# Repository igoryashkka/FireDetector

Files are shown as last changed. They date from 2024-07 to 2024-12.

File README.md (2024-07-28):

# FireDetector

## PCB and 3D-Design

| 3D-Design | PCB |
|:---:|:---:|
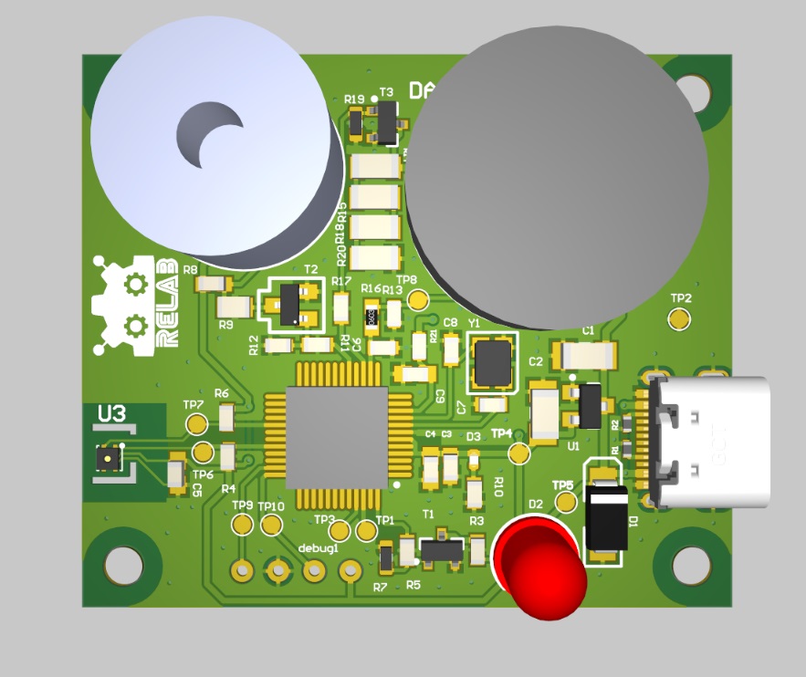
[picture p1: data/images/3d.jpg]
Input image
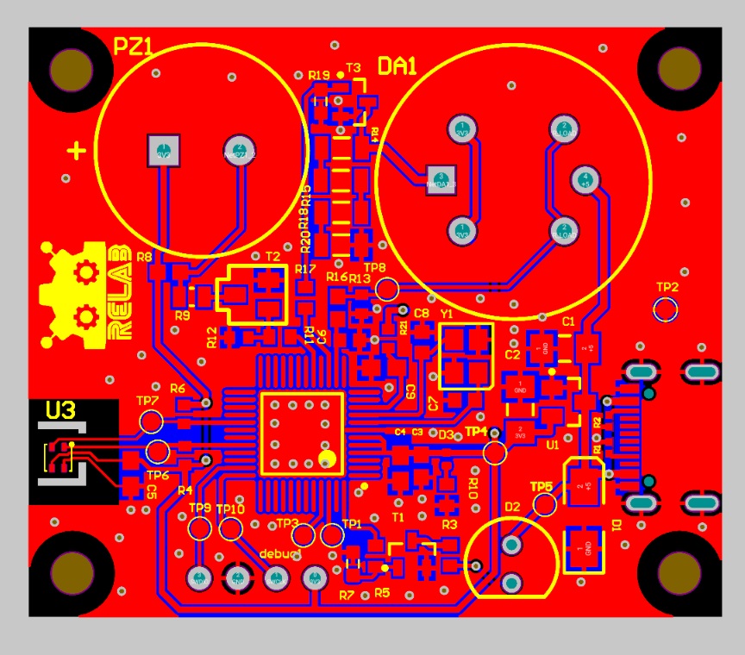
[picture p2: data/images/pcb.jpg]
Predicted mask
|  |  |

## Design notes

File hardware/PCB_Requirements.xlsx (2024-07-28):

PCB Name | Fire Detector |  | <Parameter PCB_Version not found>
Author | Ihor Yashan
Amount boards per stand | 1
Produced within | 2 weeks
Item | Requirement | Comment
Layer count | 2
Size | 42.7х38.9mm
Thickness | 1.6 mm
Material | FR-4
Min track/spacing | 0.17mm / 6mil
Min hole size | 0.3 mm
Copper weight | 1oz / 35um
Mask | on both sides
Mask color | Black
Surfaces finishing | HASL
Silkscreen | Yes
Silkscreen color | White
Board Outline, Cutout | Mechanical4 (GM4)
Electric test | Necessarily for 100% samples

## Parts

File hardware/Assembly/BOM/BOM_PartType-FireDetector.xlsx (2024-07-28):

Comment | Description | Designator | Footprint | LibRef | Quantity
100u 1206 | Multilayer Ceramic Capacitor, C Series, 100u F, - 20%, X5R, 10 V, 1206 | C1, C2 | PCB-3930564-3 | CMP-3930564-3 | 2
2.2u 0603 | Ceramic Multilayer Capacitor, 0603 C 2.2uF ,10 VDC, +125degC, X7R Dielec, +/-10% | C3 | PCB-uly74adw9ajmyngyt4c8-1 | CMP-ceff04ea830e1138-1 | 1
100n 0603 | 0603 100nF 16 V ±10% Tolerance X7R Surface Mount Multilayer Ceramic Capacitor | C4, C5, C9 | AVX 0603YC104KAZ2A | CMP-126706-3 | 3
10n 0603 | Ceramic Capacitor, Multilayer, Ceramic, 50V, 10% +Tol, 10% -Tol, X7R, 15% TC, 0.01uF, Surface Mount, 0603 | C6 | CAPC1608X90X35LL15T15 | CMP-175274-2 | 1
10p 0603 | Multilayer Ceramic Capacitor, 10 pF, 50 V, ± 5%, C0G (NP0), 0603 | C7, C8 | CAPC1608X87X35NL15T15 | CMP-4049010-3 | 2
Bourns SMAJ5.0CA | Transient Voltage Suppressor, TVS, SMAJ Series, Bidirectional, 5 V, DO-214AC, 2, 6.4 V | D1 | PCB-vtu3u1mnbo50t4of4vtk-1 | CMP-282675-5 | 1
Lite-On LTL-4223 | @LED, RED, DIFFUS, 635nm, T-1 3/4, 19mcd, VIEWING ANGLE: 36, T/REEL | D2 | PCB-jn1d7xm0frbkcgbx1k6p-1 | CMP-82c94bcbc4355d0e-4 | 1
LTST-C281KGKT | Standard LEDs - SMD SMD LED Green 571nm 35mcd 130VA 0402 | D3 | PCB-vktc7y19lroxdehs8mxv-1 | CMP-873e4eb91e2758f9-12 | 1
MQ7 | Analog Carbon Monoxide Sensor https://www.sparkfun.com/products/9403 | DA1 | sensor mq-7-Footprint-1 | CMP-a3e36b8373d07c24-5 | 1
Global Connector Technology USB4105 | Conn USB 2.0 Type C RCP 16 POS 0.3mm/0.5mm Solder RA SMD 16 Terminal 1 Port T/R | J1 | PCB-jtoj50qxusyca8vax1pa-1 | CMP-02a6cdcbf5c5dd61-15 | 1
TDK PS1420P02CT | Audio Buzzer Piezo 30Vo-p 5Vo-p 70dBA Through Hole Pin Ammo | PZ1 | PCB-snegfq1spk96rguke62s-1 | CMP-0cb8c507bf0ed37f-8 | 1
56k 0402 | Res Thick Film 0402 56K Ohm 1% 0.063W(1/16W) ±100ppm/C Pad SMD Automotive T/R | R1, R2 | PCB-q54nzy04w6wuwzvyrr10-1 | CMP-740bb86d8397abcc-1 | 2
150ohm 0603 | SMD Chip Resistor, 150 Ohm, ± 1%, 100 mW, 0603 [1608 Metric], Thin Film | R3 | RESC1608X55X30NL15T15 | CMP-3651093-2 | 1
10k 0603 | SMD Chip Resistor, 10 kOhm, ± 1%, 100 mW, 0603 [1608 Metric], Thick Film CRG0603F10K/10 | R4, R6, R12, R13, R21 | RESC1608X55X30LL15T15 | CMP-1974d512ef63c6b3-3 | 5
1k 0603 | SMD Chip Resistor, 1 kOhm, ± 1%, 330 mW, 0603 [1608 Metric], Thick Film,CHP0603-FX-1001ELF | R5, R10, R11, R17 | RESC1608X55X30NL20T10 | CMP-2823488-2 | 4
100k 0603 | Res Thick Film 0603 100K Ohm 1% 0.1W(1/10W) ±100ppm/C Pad SMD T/R | R7, R19 | PCB-js3e944hkesj3cskg8px-1 | CMP-47e38e6423219824-1 | 2
100ohm 0603 | SMD Chip Resistor, 100 Ohm, ± 1%, 100 mW, 0603 [1608 Metric], Thick Film RC0603FR-13100RL | R8 | CAPC1608X90X35NL15T15 | CMP-cc630402cb1d13a4-1 | 1
0ohm 0805 | RES SMD 0.0 OHM JUMPER 1/8W 0805 | R9 | RESC2013X50X30LL20T20 | CMP-1904075-2 | 1
22ohm 1206 | SMD Chip Resistor, 22 Ohm, ± 1%, 250 mW, 1206 [3216 Metric], Thick Film RC1206FR-0722RL | R14, R15, R18, R20 | RESC3216X70X50LL05T20 | CMP-3707874-2 | 4
200ohm 0603 | SMD Chip Resistor, 200 Ohm, ± 1%, 100 mW, 0603 [1608 Metric], Thick Film, General Purpose | R16 | CAPC1608X90X35NL15T15 | CMP-dd0d170937a802ca-2 | 1
IRLML6244TRPBF | Single N-Channel 20 V 1.3 W 8.9 nC HexFet Power Mosfet Surface Mount - SOT-23-3 | T1, T3 | PCB-05ns9k6nv0txgfjo8w7e-1 | CMP-7c86b4929b0ea341-4 | 2
BC847B,215 | TRANS NPN 45V 0.1A SOT23 | T2 | SOT23-BEC | CMP-856282-5 | 1
Torex Semiconductor XC6206P332MR | Low ESR Cap. Compatible Positive Voltage Regulator | U1 | SOT23-3 | CMP-3784183-12 | 1
STMicroelectronics STM32G030C8T6 | MCU 32-Bit STM32G030 ARM Cortex-M0+ RISC 64KB Flash 2V to 3.6V 48-Pin LQFP Tray | U2 | STM-LQFP48_M | CMP-eb4c2469bd74348b-7 | 1
SHT41 | SHT4x Series 3.6 V 80% RH 4th Generation Digital Humidity and Temperature Sensor | U3 | PCB-dp4eo4jstscfxnaq393n-1 | CMP-893b468f277b56fc-2 | 1
8Mhz 3.2 x 2.5 x 0.8mm_x0008__x0008__x0008__x0008__x0008__x0008_ | Abracon ABM8AIG-8.000MHZ-8-V1R-T Crystal Crystal 0.031 0.80mm -40C~150C 500Ohm | Y1 | ABM8AIG-4-Lead | CMP-76f4bbcd6863a933-3 | 1

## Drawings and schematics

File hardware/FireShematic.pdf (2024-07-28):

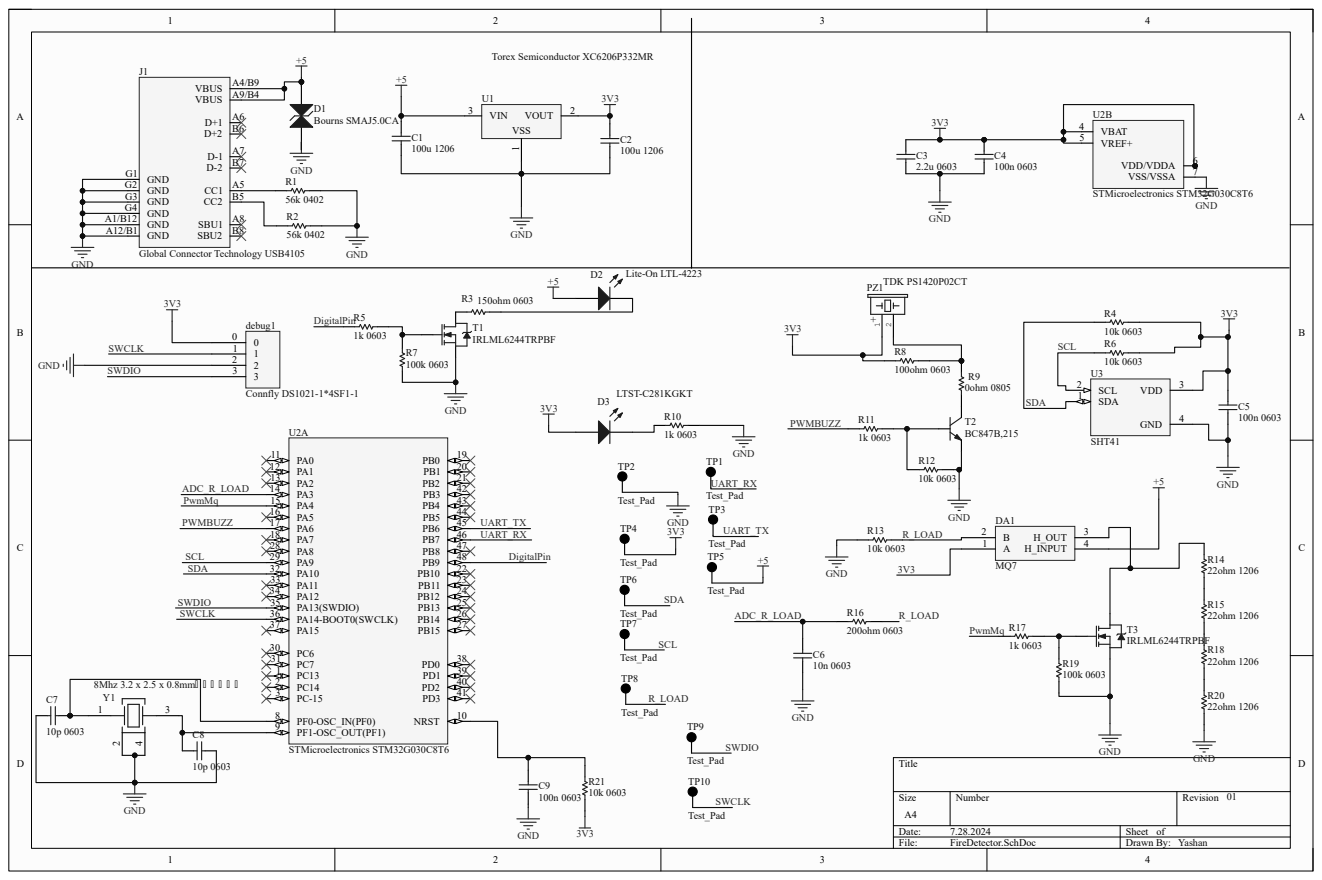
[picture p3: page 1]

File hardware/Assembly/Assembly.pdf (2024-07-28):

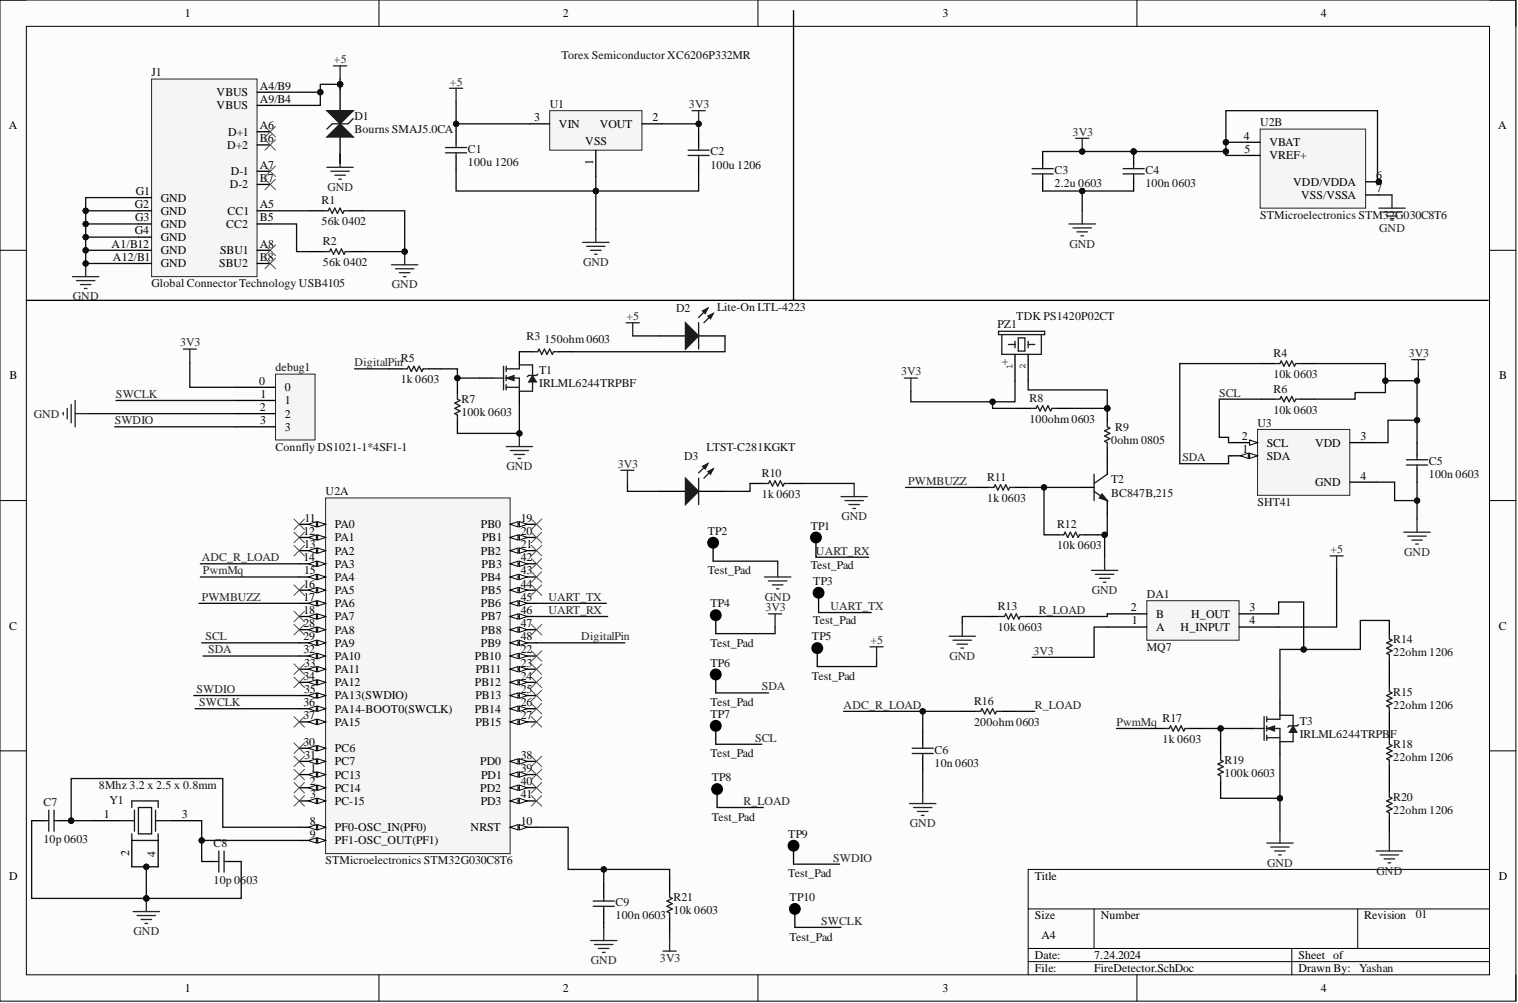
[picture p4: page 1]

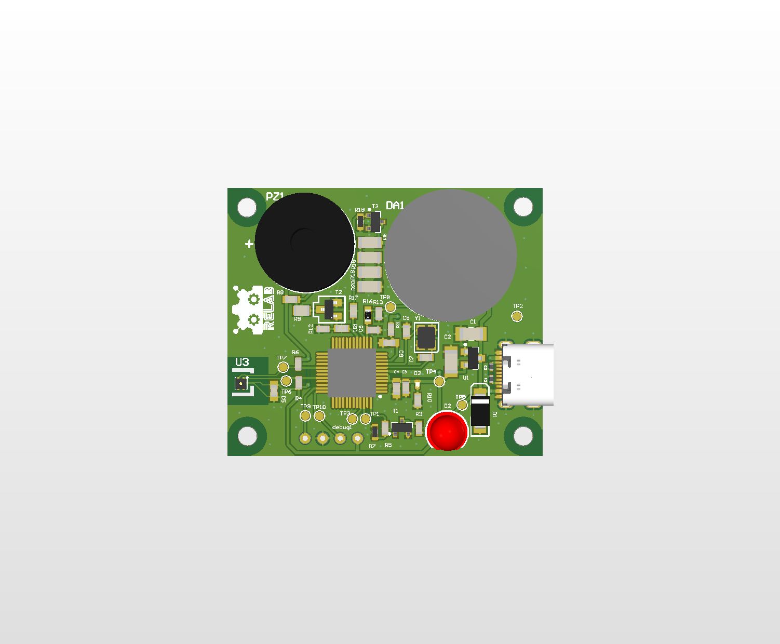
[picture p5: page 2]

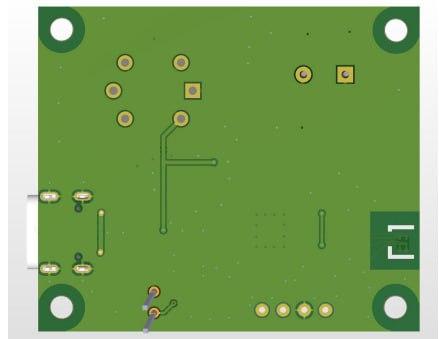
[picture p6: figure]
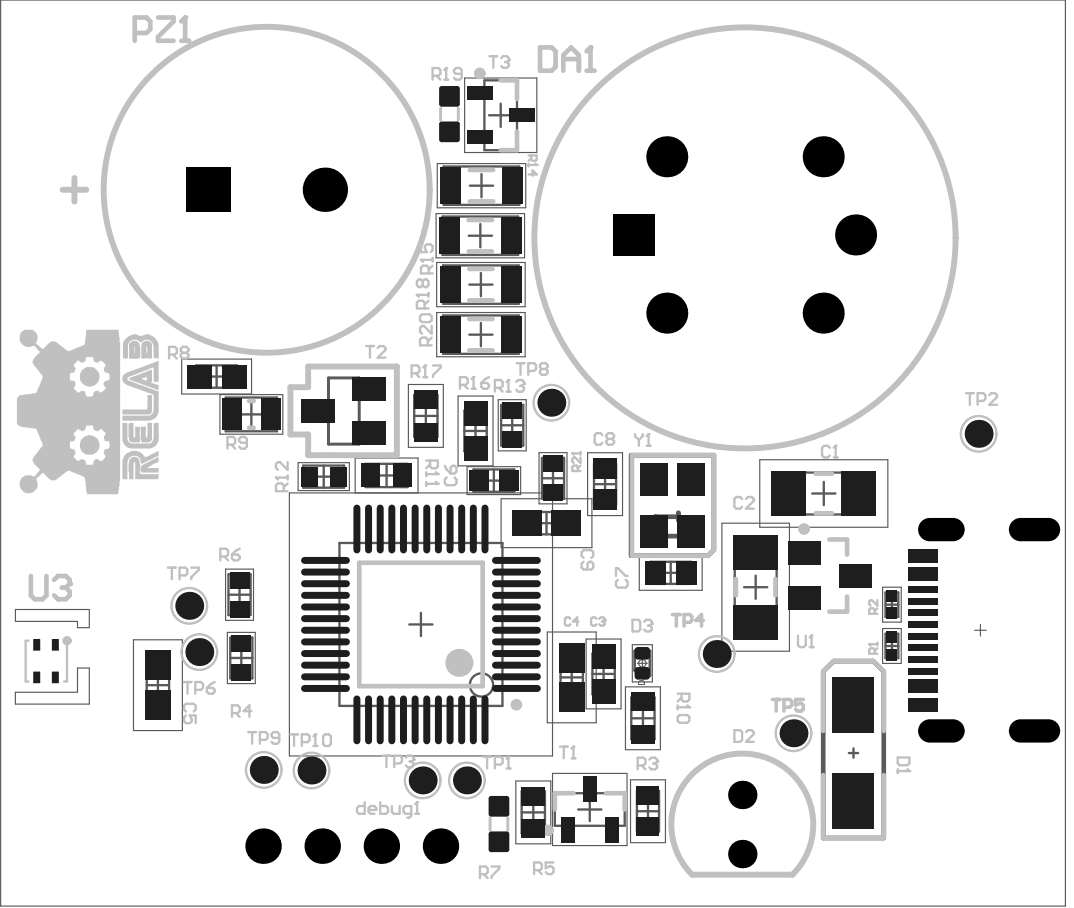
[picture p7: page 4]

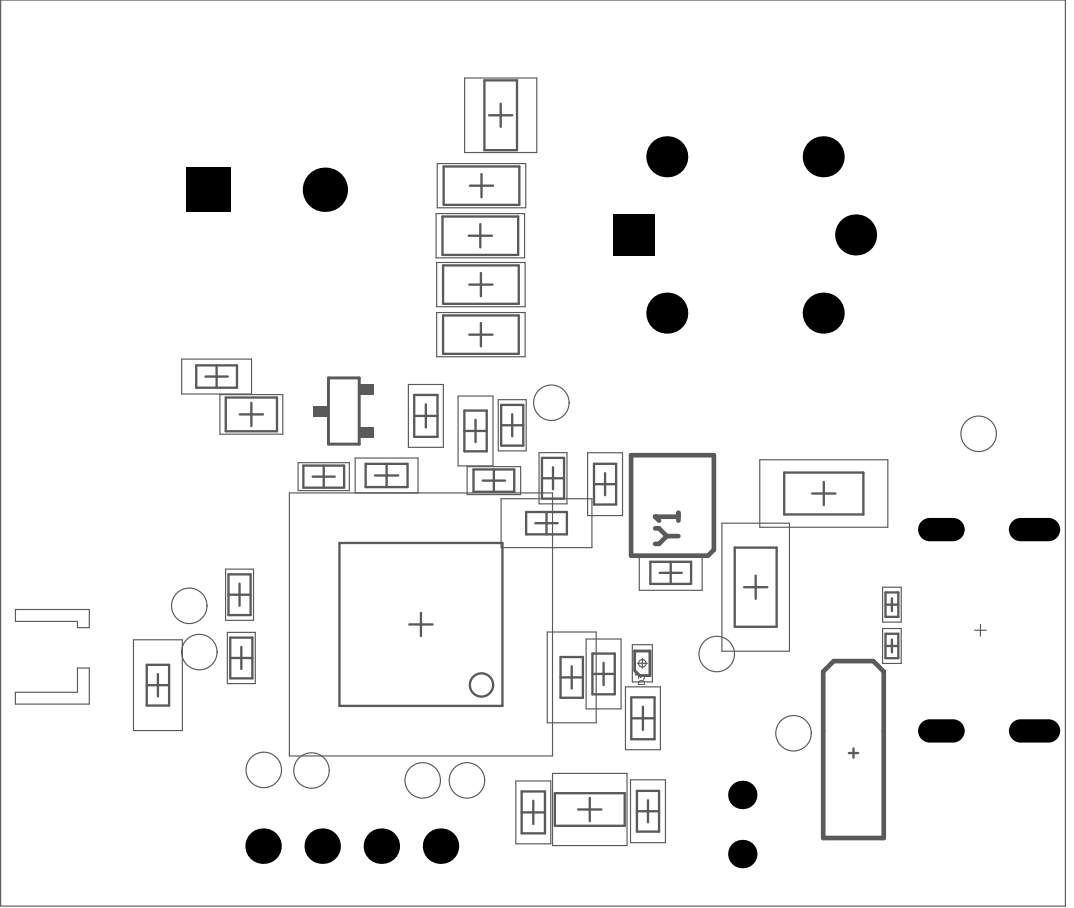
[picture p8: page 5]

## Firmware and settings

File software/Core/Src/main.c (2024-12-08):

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
/* Includes ------------------------------------------------------------------*/
#include "main.h"
#include <stdio.h>
#include <string.h>
/* USER CODE BEGIN PD */
#define LIMIT_TEMP 		50
#define LIMIT_CO_PPM 	150
#define LIMIT_HUMIDITY 	30

#define TEMP_ANOMALY_THRESHOLD     10
#define CO_ANOMALY_THRESHOLD       20
#define HUMIDITY_ANOMALY_THRESHOLD 10
#define ANOMALY_INTERVAL           3000

#define HEATER_INTERVAL 21600000  				// 6 hours
#define HEATER_RUN_TIME 10000    				// 10 seconds


uint32_t value_ppm = 0;								// Global var used in driver_mq.c
uint8_t can_process_uart = 1;

uint8_t uart1_rx_buffer[SIZE_UART_RX_BUFFER] = {0};
char uart_command[SIZE_UART_RX_BUFFER] = {0};
uint8_t uart_command_ready = 0;

/* USER CODE END PD */

ADC_HandleTypeDef hadc1;

I2C_HandleTypeDef hi2c1;

TIM_HandleTypeDef htim1;
TIM_HandleTypeDef htim3;
TIM_HandleTypeDef htim14;
TIM_HandleTypeDef htim16;
TIM_HandleTypeDef htim17;

UART_HandleTypeDef huart1;

void SystemClock_Config(void);
static void MX_GPIO_Init(void);
static void MX_TIM17_Init(void);
static void MX_TIM16_Init(void);
static void MX_ADC1_Init(void);
static void MX_I2C1_Init(void);
static void MX_TIM14_Init(void);
static void MX_TIM3_Init(void);
static void MX_TIM1_Init(void);
static void MX_USART1_UART_Init(void);
/**
  * @brief  The application entry point.
  * @retval int
  */
int main(void)
{
  /* MCU Configuration--------------------------------------------------------*/

  /* Reset of all peripherals, Initializes the Flash interface and the Systick. */
  HAL_Init();

  /* Configure the system clock */
  SystemClock_Config();

  /* Initialize all configured peripherals */
  MX_GPIO_Init();
  MX_TIM17_Init();
  MX_TIM16_Init();
  MX_ADC1_Init();
  MX_I2C1_Init();
  MX_TIM14_Init();
  MX_TIM3_Init();
  MX_TIM1_Init();
  MX_USART1_UART_Init();
  /* USER CODE BEGIN 2 */
  HAL_TIM_PWM_Start(&htim17, TIM_CHANNEL_1);//hw_init
  HAL_TIM_PWM_Start(&htim16, TIM_CHANNEL_1);//hw_init
  //mq init :
  HAL_TIM_PWM_Start(&htim14, TIM_CHANNEL_1);//hw_init
  HAL_TIM_Base_Start(&htim1);
  //UART init in interrupt mode
  HAL_UART_Receive_IT (&huart1, uart1_rx_buffer, SIZE_UART_RX_BUFFER);
  /* USER CODE END 2 */

  /* Infinite loop */
  /* USER CODE BEGIN WHILE */
  while (1)
  {
	  	MQ_run_mesurments();
	  	SHT_process_mesuremnts();
	  	if (uart_command_ready && can_process_uart) {
	  		uart_command_ready = 0;
	  	    Process_UART_Command(uart_command);
	  	    uart_command[0] = '\0';
	  	}
    /* USER CODE END WHILE */

    /* USER CODE BEGIN 3 */
  }
  /* USER CODE END 3 */
}

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
/* USER CODE BEGIN 4 */
void SHT_process_mesuremnts(void)
{

  HAL_StatusTypeDef sht_status;

	float prev_temperature = 0, prev_humidity = 0;
	uint32_t prev_ppm = 0;
	uint32_t last_anomaly_check = 0;
	uint32_t last_heater_activation = 0;
	uint32_t heater_end_time = 0;
	float temperature = 0, humidity = 0;
	uint32_t current_time = 0;
	uint8_t fire_detected = 0, emergency_triggered = 0;
    current_time = HAL_GetTick();


    if (current_time - last_heater_activation >= HEATER_INTERVAL) {
        sht_status = SHT41_Activate_Heater(SHT41_HEATER_200MW_1S);
        if (sht_status == HAL_ERROR) {
            temperature = 0; humidity = 0; value_ppm = 0; prev_temperature = 0; prev_humidity = 0; prev_ppm = 0;
            Signal_error();
            return;
        }
        heater_end_time = current_time + HEATER_RUN_TIME;
        last_heater_activation = current_time;
        can_process_uart = 0;
    }

    if (current_time < heater_end_time) {
    	can_process_uart = 0;
        return;  // Block measurements during heater operation
    }

    can_process_uart = 1;

    sht_status = SHT41_Read_Temperature_Humidity(SHT41_MEASURE_HIGHREP_STRETCH, &temperature, &humidity);
    if (sht_status == HAL_ERROR) {
        temperature = 0; humidity = 0; value_ppm = 0; prev_temperature = 0; prev_humidity = 0; prev_ppm = 0;
        Signal_error();
        return;
    }

    if (current_time - last_anomaly_check >= ANOMALY_INTERVAL) {
        emergency_triggered = 0;
        if ((temperature - prev_temperature > TEMP_ANOMALY_THRESHOLD) ||
            (value_ppm - prev_ppm > CO_ANOMALY_THRESHOLD) ||
            (prev_humidity - humidity > HUMIDITY_ANOMALY_THRESHOLD)) {

            Signal_detect_emergency();
            emergency_triggered = 1;
        }
        prev_temperature = temperature;
        prev_ppm = value_ppm;
        prev_humidity = humidity;
        last_anomaly_check = current_time;
    }

    if (!emergency_triggered) {
        if (temperature > LIMIT_TEMP && value_ppm > LIMIT_CO_PPM && humidity < LIMIT_HUMIDITY) {
            Signal_detect_fire();
            fire_detected = 1;
        } else if (temperature > LIMIT_TEMP || value_ppm > LIMIT_CO_PPM) {
            Signal_detect_emergency();
        } else {
            Signal_idle_state();
            fire_detected = 0;
        }
    } else {
        Signal_idle_state();
    }
}


void Process_UART_Command(char *command) {
    float temperature = 0, humidity = 0;
    uint8_t uart1_tx_buffer[SIZE_UART_TX_BUFFER] = {0};

    if (command[0] == '\0') {
        return;
    }

    if (strcmp(command, "get_humidity") == 0) {
        SHT41_Read_Temperature_Humidity(SHT41_MEASURE_HIGHREP_STRETCH, &temperature, &humidity);
        snprintf((char*)uart1_tx_buffer, SIZE_UART_TX_BUFFER, "DEV: get_humidity %.1f\n", humidity);
    } else if (strcmp(command, "get_temperature") == 0) {
        SHT41_Read_Temperature_Humidity(SHT41_MEASURE_HIGHREP_STRETCH, &temperature, &humidity);
        snprintf((char*)uart1_tx_buffer, SIZE_UART_TX_BUFFER, "DEV: get_temperature %.1f\n", temperature);
    } else if (strcmp(command, "get_ppm") == 0) {
        snprintf((char*)uart1_tx_buffer, SIZE_UART_TX_BUFFER, "DEV: get_ppm %ld\n", value_ppm);
    } else if (strncmp(command, "set_buzzer ", 11) == 0) {
        if (strcmp(&command[11], "on") == 0) {
            Buzzer_On();
            snprintf((char*)uart1_tx_buffer, SIZE_UART_TX_BUFFER, "DEV response: set_buzzer on\n");
        } else if (strcmp(&command[11], "off") == 0) {
            Buzzer_Off();
            snprintf((char*)uart1_tx_buffer, SIZE_UART_TX_BUFFER, "DEV response: set_buzzer off\n");
        }
    } else if (strncmp(command, "set_led ", 8) == 0) {
        if (strcmp(&command[8], "on") == 0) {
            LED_On();
            snprintf((char*)uart1_tx_buffer, SIZE_UART_TX_BUFFER, "DEV response: set_led on\n");
        } else if (strcmp(&command[8], "off") == 0) {
            LED_Off();
            snprintf((char*)uart1_tx_buffer, SIZE_UART_TX_BUFFER, "DEV response: set_led off\n");
        }
    } else {
        snprintf((char*)uart1_tx_buffer, SIZE_UART_TX_BUFFER, "DEV: unknown_command\n");
    }
    HAL_UART_Transmit(&huart1, uart1_tx_buffer, strlen((char*)uart1_tx_buffer), HAL_MAX_DELAY);
}

/* USER CODE END 4 */
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


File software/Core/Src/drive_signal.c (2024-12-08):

#include "drive_signal.h"

// ---------- LED Control ------------------------- //
void LED_SetBrightness(uint16_t brightness)
{
	__HAL_TIM_SET_COMPARE(&htim17, TIM_CHANNEL_1, brightness);
}

void LED_Off(void)
{
    LED_SetBrightness(0);
}

void LED_On(void)
{
    LED_SetBrightness(65535);
}

void LED_Blink_Start(uint16_t period)
{

    HAL_TIM_Base_Stop_IT(&htim3); // Stop the timer first if it was running
    __HAL_TIM_SET_AUTORELOAD(&htim3, period - 1); // Set the period for blinking
    HAL_TIM_Base_Start_IT(&htim3); // Start the timer interrupt
}

void LED_Blink_Stop(void)
{
    HAL_TIM_Base_Stop_IT(&htim3); // Stop the timer interrupt
    LED_Off();
}

// ---------- Buzzer Control ---------------------- //
void Buzzer_SetVolume(uint16_t volume)
{
    __HAL_TIM_SET_COMPARE(&htim16, TIM_CHANNEL_1, volume);
}

void Buzzer_Off(void)
{
    Buzzer_SetVolume(0);
}

void Buzzer_On(void)
{
    Buzzer_SetVolume(htim16.Init.Period / 2);
}


// ---------- Signaling Functions ---------------------- //


void Signal_error(void) {
    LED_Blink_Start(5000);
}


void Signal_idle_state(void)
{
	LED_Blink_Stop();
	LED_On();
    Buzzer_Off();
}

void Signal_detect_emergency(void)
{
    LED_Blink_Start(500);
    Buzzer_On();
}

void Signal_detect_fire(void)
{
    LED_Blink_Start(100);
    Buzzer_On();
}

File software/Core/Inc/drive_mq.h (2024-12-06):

#ifndef MQ_SENSOR_H
#define MQ_SENSOR_H

// -------------- INCLUDE AREA ----------------------------------- //

#include "stm32g0xx_hal.h"
#include "drive_signal.h"
#include <math.h>

// -------------- MACRO AND DEFINES AREA ------------------------- //
#define MQ7_LOAD_RESISTOR 			10000
#define REF_VOLTAGE 	  			3.3
#define MQ7_RO 	      				10000 // Resistance of sensor within 100ppm (in Ohm)
#define NUM_READ 		  			1000
#define BIT_ADC_VALUE	  			4095
#define TIMER_PERIOD_30SEC_HEAT		29999
#define TIMER_PERIOD_60SEC_HEAT		59998
#define TIMER_PERIOD_60SEC_MESURE	59999
#define PERIOD_2_HEAT				2
#define PERIOD_1_HEAT				1
#define PERIOD_MESURE				0
#define OFFSET_PERIOD_MESURE		5500
#define MAX_VALUE_PPM    			3999
// -------------------------

// -------------------------
extern ADC_HandleTypeDef hadc1;
extern TIM_HandleTypeDef htim1;
extern TIM_HandleTypeDef htim14;

// -------------- FUNCTION DECLARATIONS AREA --------------------- //
float read_voltage();
uint32_t convert_voltage_to_ppm(float mq7_volts);
void MQ_run_mesurments();

#endif // MQ_SENSOR_H

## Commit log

2024-07-28 add hardware implementation
    [BOM_PartType-FireDetector.xlsx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]
2024-08-26 edit settings for timers, add SHT lib, add logic to main.c
2024-08-26 add TIM3 for led blinking , add Drive_signal lib, add logic for test states
2024-12-01 remove trash-code, remove global vars, add processing uart
2024-12-06 clean sht-code, add uart parse, edit logic for sht mesurments
2024-12-06 add validation checks for sensors
2024-12-08 with O1 25% free flash mem, move processing uart, improve handling uart, delete sht heater going at the start.
2024-12-08 add flag to check if measurements is not blocked to req uart

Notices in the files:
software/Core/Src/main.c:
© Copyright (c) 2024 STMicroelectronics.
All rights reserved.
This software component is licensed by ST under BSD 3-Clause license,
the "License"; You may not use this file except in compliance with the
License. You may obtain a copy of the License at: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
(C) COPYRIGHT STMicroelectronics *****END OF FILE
